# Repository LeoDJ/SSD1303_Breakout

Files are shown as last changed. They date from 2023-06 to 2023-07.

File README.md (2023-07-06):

# SSD1303 Breakout Board

A breakout board for a specific SSD1303 OLED display.  
Optimized for low-cost PCB assembly services from a specific chinese manufacturer with blue logo.

You can [preview the PCB](https://kicanvas.org/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) using the amazing KiCanvas. (Or the [schematic](https://kicanvas.org/?github=https%3A%2F%2Fgithub.com%2FLeoDJ%2FSSD1303_Breakout%2Ftree%2Fmain) if I forget to update the [PDF](./SSD1303_Breakout.pdf) ^^' )

## Pinout
| Pin | Function |
|-----|---|
| GND | GND |
| VCC | 3.3 - 5 V (up to ~250mA[^1]) |
| CLK | SPI: `SCK` <br>I²C: `SCL` |
| DI  | SPI: `MOSI` <br>I²C: `SDA` |
| RES | Reset (active low) |
| DC  | SPI: data/command line <br>I²C: address. 0: `0x3C` / 1: `0x3D` (default low) |
| CS  | SPI: `CS` |

* I/O pins are 5V tolerant
* To switch between SPI and I²C mode, you need to bridge / unbridge the solder jumper at the back (default is SPI)
* I've tried to make the pinout as compatible as possible to existing OLED modules, but there are many different variants

[^1]: Might draw up to ~250 mA @ 3.3V with all pixels on, guesstimated.  
I've measured roughly 50mA @ 12V with the highest brightness and all pixels on, so with pessimistic conversion losses around 750mW.

## Rev 1.0
### Issues
- In SPI mode, the "serial data out" pin of the SSD1303 (pin D2) doesn't always stay high[^2], as was initially measured. Thus the simple diode trick to allow both SPI and I²C mode, without needing to "keep D2 disconnected in SPI mode" as stated in the datasheet, won't work.
  - **Workaround**: Remove D1 (below the FPC) for working SPI mode
  - Fix in next revision: An additional FET in series to the D2 signal that gets activated by the solder jumper
- An additional solder jumper for I²C address would probably be nice
  - In case one wants to use the breakout board on a 4-pin-only socket
  - **Workaround**: solder a jumper wire from the DC pin/pad to the VCC pin/pad to select address `0x3D`

[^2]: It appears to shift out some kind of data, maybe from an internal register. The SSD1303 datasheet doesn't give any hint to the behaviour of pin D2 in SPI mode, except to keep it disconnected.  
Over time the value that gets shifted out accumulates 1 bits. Starting at some random value with few bits set on power-up. (It probably turns into a constant high signal as soon as it reaches 0xFF, but I could only actually observe it up to 0x7F/0xF7 in my last measurement.)  
When the pin is actively pulled low by the SSD1303, it interferes through the diode D1 with the actual data meant for the data input pin D1.  

### Screenshots of 3D view
Somehow I got a bit carried away for a relatively simple design, but otoh I've learned a lot again.

<p float="left" style="display: flex; flex-wrap: wrap; align-items: center;">
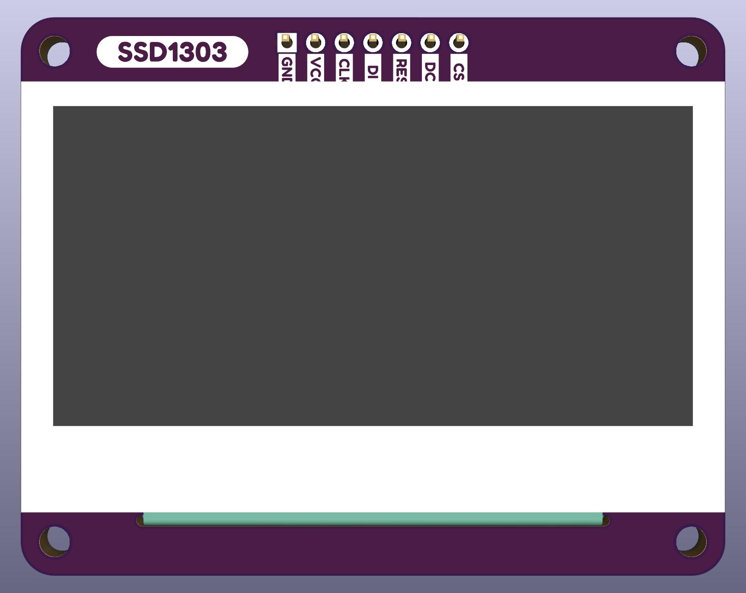
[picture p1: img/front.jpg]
  &nbsp;
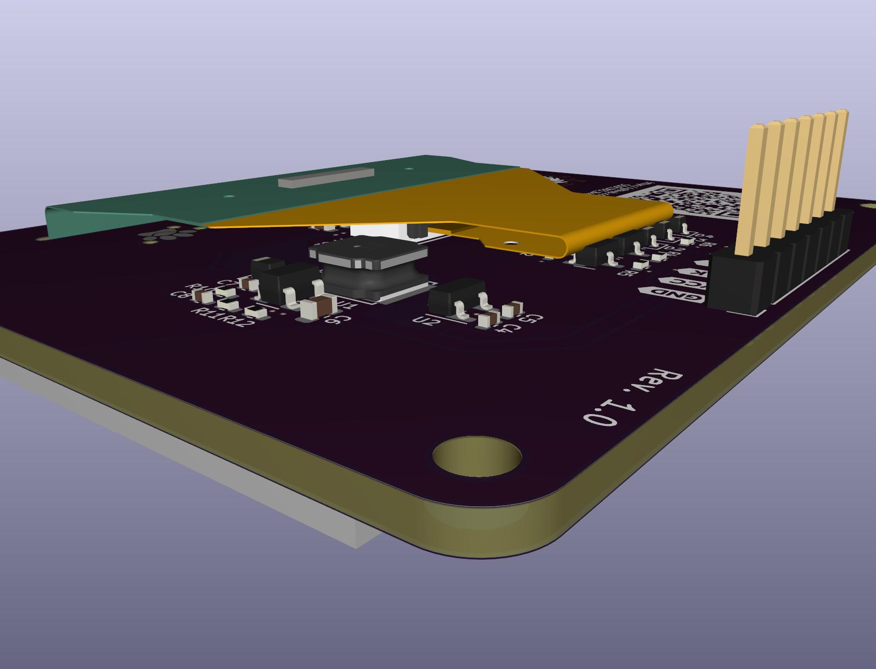
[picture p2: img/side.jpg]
  
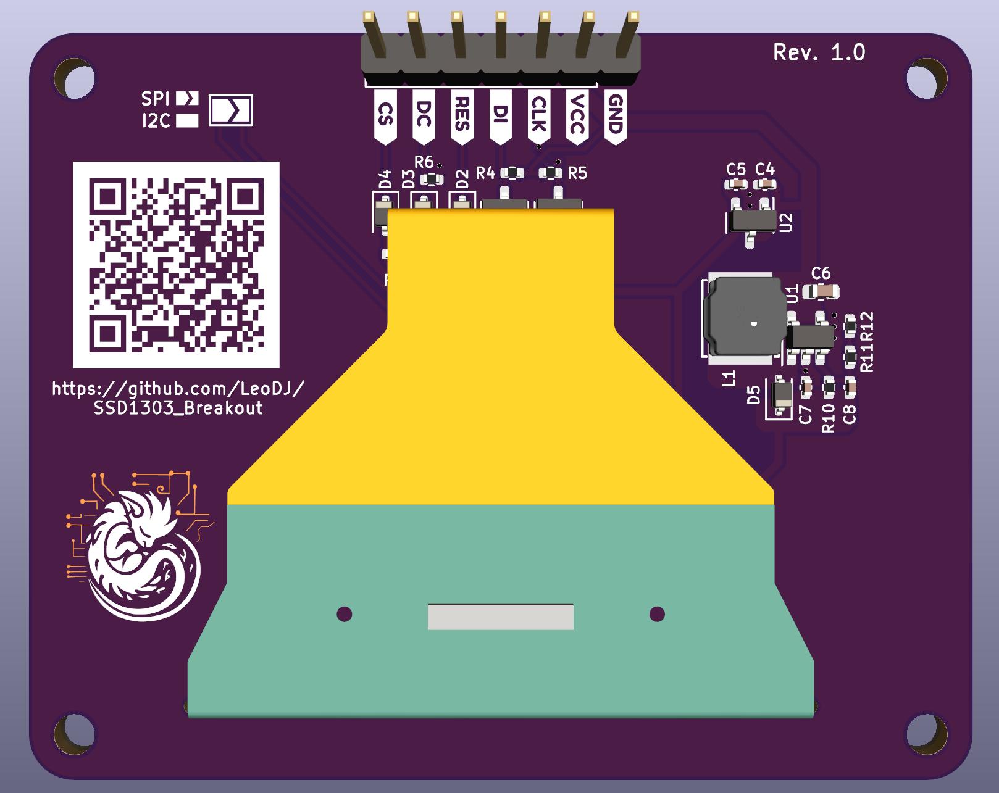
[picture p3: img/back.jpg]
  &nbsp;
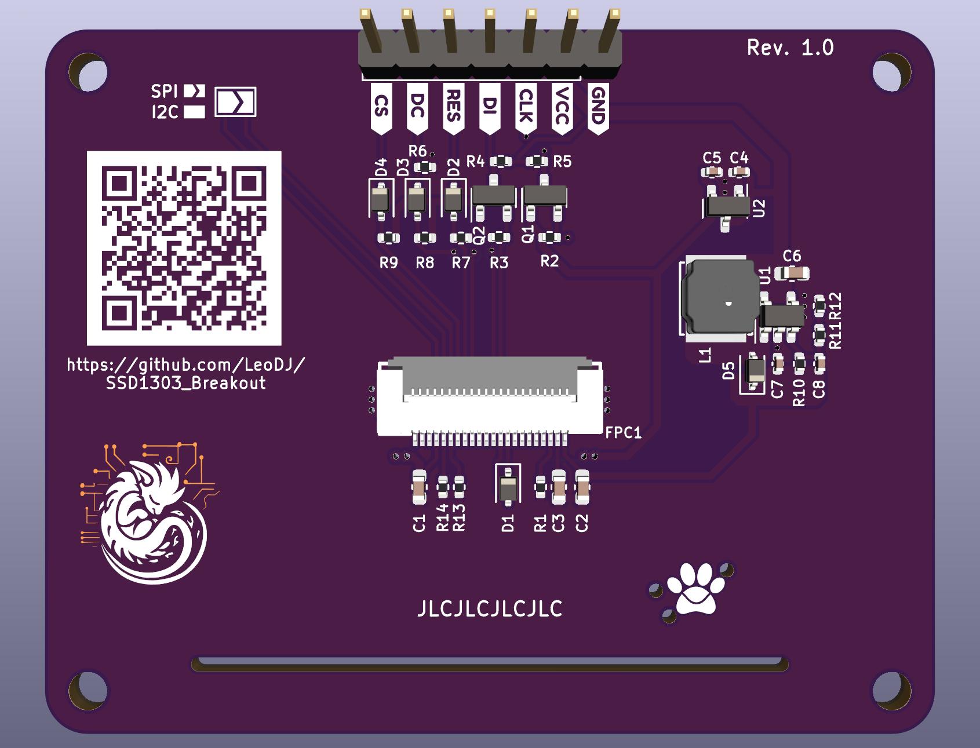
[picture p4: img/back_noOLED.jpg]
  
</p>

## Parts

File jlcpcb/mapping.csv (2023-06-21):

Footprint | Part Value | LCSC Part
C_0402_1005Metric | 1u | C52923
C_0402_1005Metric | 1uF/25V | C52923
C_0402_1005Metric | 10p | C32949
C_0603_1608Metric | 10u | C96446
C_0603_1608Metric | 10uF/25V | C96446
D_SOD-323 | 1N5819WS | C191023
FFC-SMD_22P-P0.50-P0.50_LW05201-22 | LW05201-22 | C375902
IND-SMD_L5.0-W5.0 | 10uH/<250mΩ | C963773
R_0402_1005Metric | 1M | C26083
R_0402_1005Metric | 10k | C25744
R_0402_1005Metric | 100k | C25741
SOT-23 | 2N7002 | C8545
SOT-23-3 | XC6206P332MR | C5446
SOT-23-5 | TPS61040DBV | C7722
TE_2-1734839-2_1x22-1MP_P0.5mm_Horizontal | Conn_01x23 | C375902

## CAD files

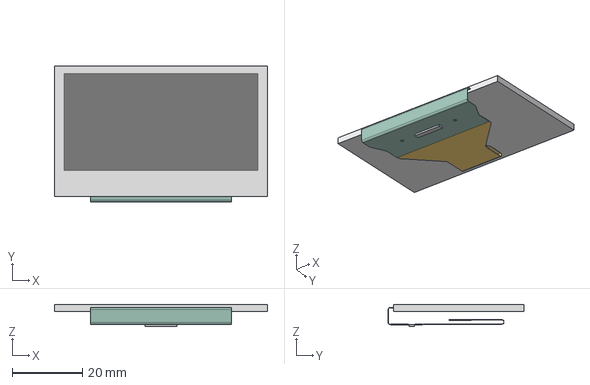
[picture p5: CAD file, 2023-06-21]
EPR1200043B SSD1303 OLED bent 1.6mm.step
60.5 x 38.6 x 6.38 mm

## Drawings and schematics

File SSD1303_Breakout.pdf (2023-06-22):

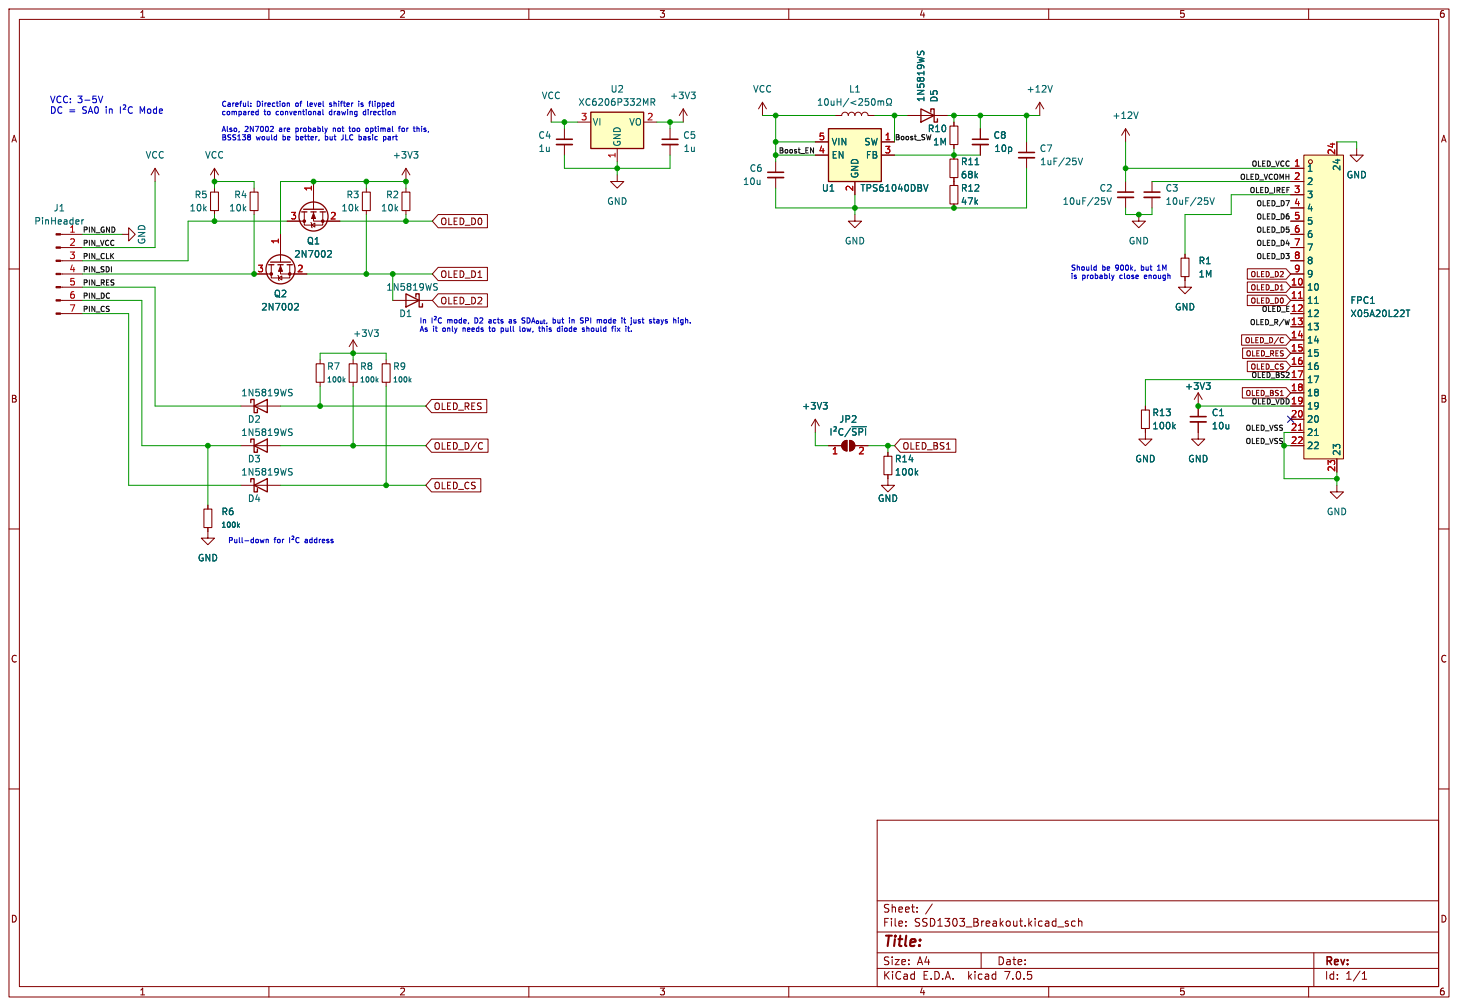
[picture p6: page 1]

2 FB 3 EN 4 VIN 5U1 TPS61040DBV GND GND 1N5819WS D5 GND

2 FB 3 EN 4 VIN 5 1N5819WS D5 GND
10uVCC

In þÿI²Cmode, D2 acts as SDA_{out},but in SPI mode it just stays high. As it only needs to pull low, this diode should fix it. VCC: 3-5V DC = SA0 in þÿI²CMode

Id: 1/1 Title: File: SSD1303_Breakout.kicad_sch Sheet: /

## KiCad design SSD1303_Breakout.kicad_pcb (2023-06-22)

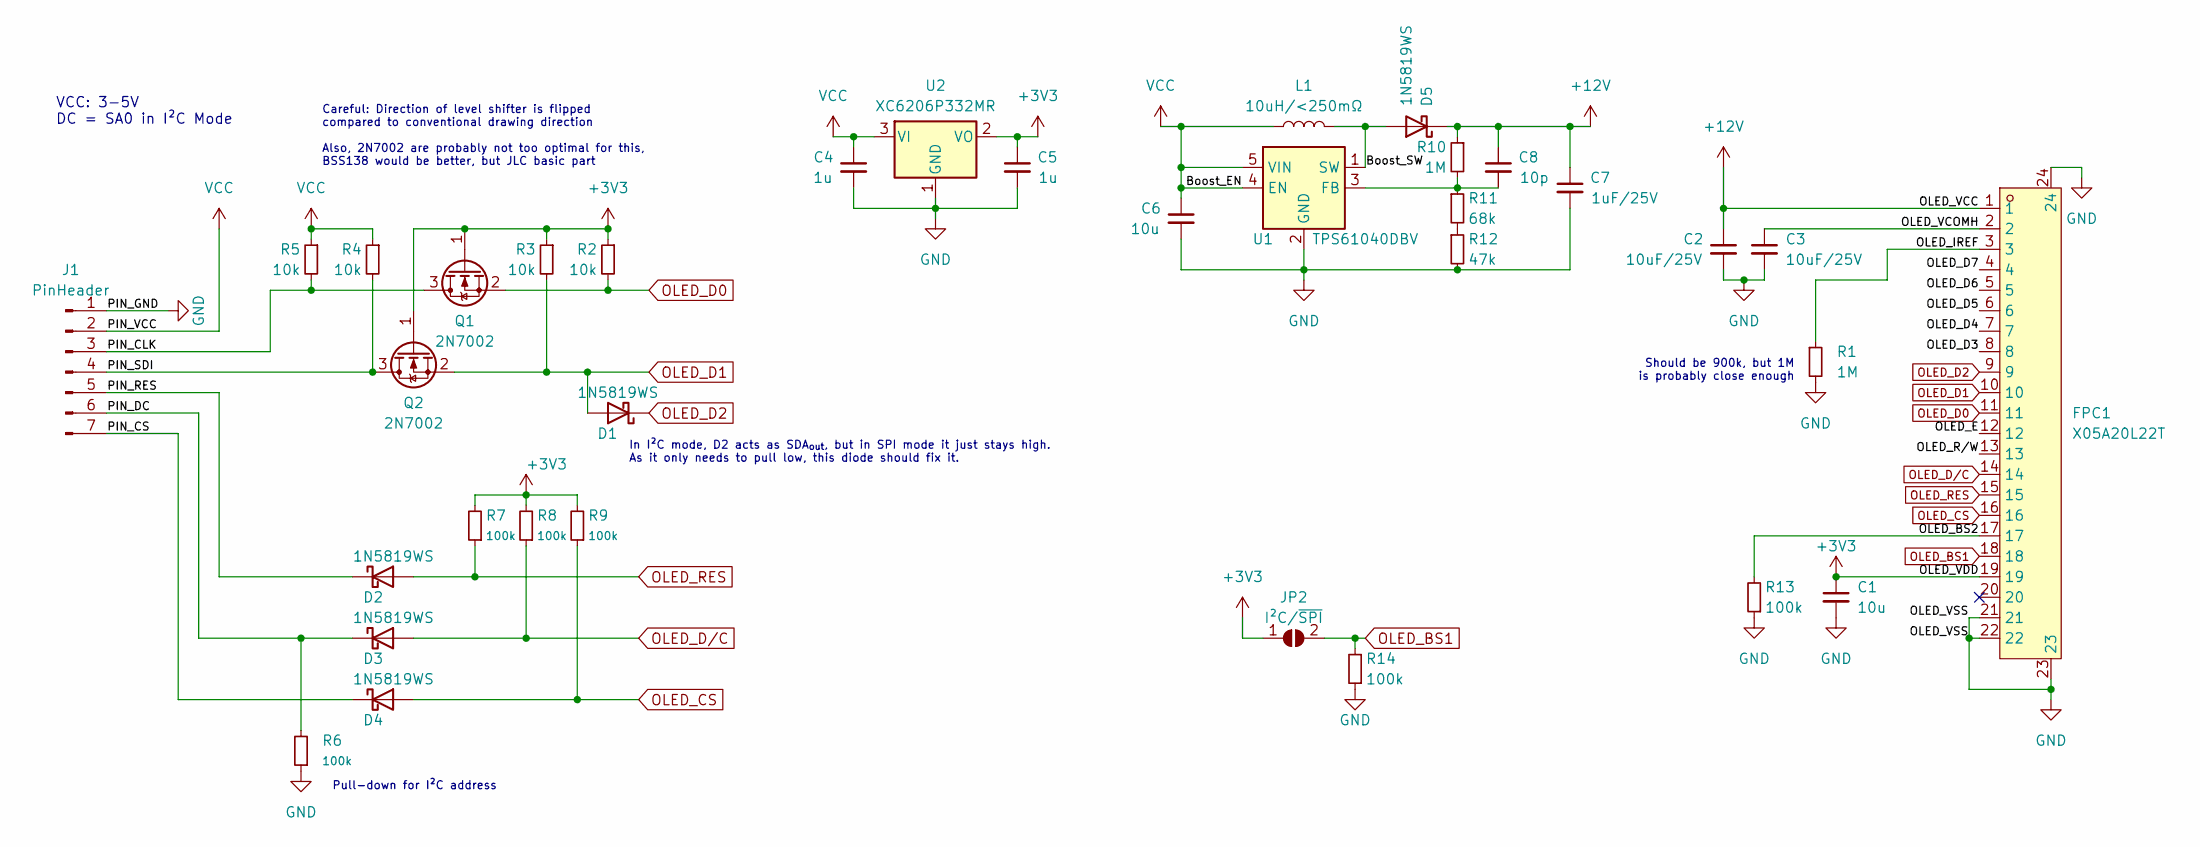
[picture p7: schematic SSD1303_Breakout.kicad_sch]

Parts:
C1, C6: 10u; C_0603_1608Metric; LCSC C96446
C2, C3: 10uF/25V; C_0603_1608Metric; LCSC C96446
C4, C5: 1u; C_0402_1005Metric; LCSC C52923
C7: 1uF/25V; C_0402_1005Metric; LCSC C52923
C8: 10p; C_0402_1005Metric; LCSC C32949
D1, D2, D3, D4, D5: 1N5819WS; D_SOD-323; LCSC C191023
FPC1: X05A20L22T; FFC-SMD_22P-P0.50_X05A20L22T; LCSC Part C388675
J1: PinHeader; PinHeader_1x07_P2.54mm_Vertical
JP2: I²C/~{SPI}; SolderJumper-2_P1.3mm_Open_TrianglePad1.0x1.5mm
L1: 10uH/<250mΩ; IND-SMD_L5.0-W5.0; LCSC C963773
Q1, Q2: 2N7002; SOT-23; LCSC C8545
R1, R10: 1M; R_0402_1005Metric; LCSC C26083
R2, R3, R4, R5: 10k; R_0402_1005Metric; LCSC C25744
R6, R7, R8, R9, R13, R14: 100k; R_0402_1005Metric; LCSC C25741
R11: 68k; R_0402_1005Metric; LCSC C36871
R12: 47k; R_0402_1005Metric; LCSC C25792
U1: TPS61040DBV; SOT-23-5; LCSC C7722
U2: XC6206P332MR; SOT-23; LCSC C5446

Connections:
+3V3: C1.1, C5.1, FPC1.19, JP2.1 (A), Q1.1 (G), Q2.1 (G), R2.1, R3.1, R7.2, R8.2, R9.2, U2.2 (VO)
+12V: C2.1, C7.1, C8.1, D5.1 (K), FPC1.1, R10.1
/Boost_SW: D5.2 (A), L1.2, U1.1 (SW)
/OLED_BS2: FPC1.17, R13.2
/OLED_D3: FPC1.8
/OLED_D4: FPC1.7
/OLED_D5: FPC1.6
/OLED_D6: FPC1.5
/OLED_D7: FPC1.4
/OLED_E: FPC1.12
/OLED_IREF: FPC1.3, R1.1
/OLED_R/W: FPC1.13
/OLED_VCOMH: C3.1, FPC1.2
/PIN_CLK: J1.3, Q1.3 (D), R5.2
/PIN_CS: D4.1 (K), J1.7
/PIN_DC: D3.1 (K), J1.6, R6.2
/PIN_RES: D2.1 (K), J1.5
/PIN_SDI: J1.4, Q2.3 (D), R4.2
GND: C1.2, C2.2, C3.2, C4.2, C5.2, C6.2, C7.2, FPC1.21, FPC1.22, FPC1.23, FPC1.24, J1.1, R1.2, R6.1, R12.2, R13.1, R14.1, U1.2 (GND), U2.1 (GND)
unnamed: R11.2, R12.1
unnamed: C8.2, R10.2, R11.1, U1.3 (FB)
OLED_BS1: FPC1.18, JP2.2 (B), R14.2
OLED_CS: D4.2 (A), FPC1.16, R9.1
OLED_D0: FPC1.11, Q1.2 (S), R2.2
OLED_D1: D1.2 (A), FPC1.10, Q2.2 (S), R3.2
OLED_D2: D1.1 (K), FPC1.9
OLED_D/C: D3.2 (A), FPC1.14, R8.1
OLED_RES: D2.2 (A), FPC1.15, R7.1
VCC: C4.1, C6.1, J1.2, L1.1, R4.1, R5.1, U1.4 (EN), U1.5 (VIN), U2.3 (VI)

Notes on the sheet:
Should be 900k, but 1M is probably close enough
In I²C mode, D2 acts as SDA_{out}, but in SPI mode it just stays high. As it only needs to pull low, this diode should fix it.
Pull-down for I²C address
Careful: Direction of level shifter is flipped compared to conventional drawing direction Also, 2N7002 are probably not too optimal for this, BSS138 would be better, but JLC basic part
VCC: 3-5V DC = SA0 in I²C Mode

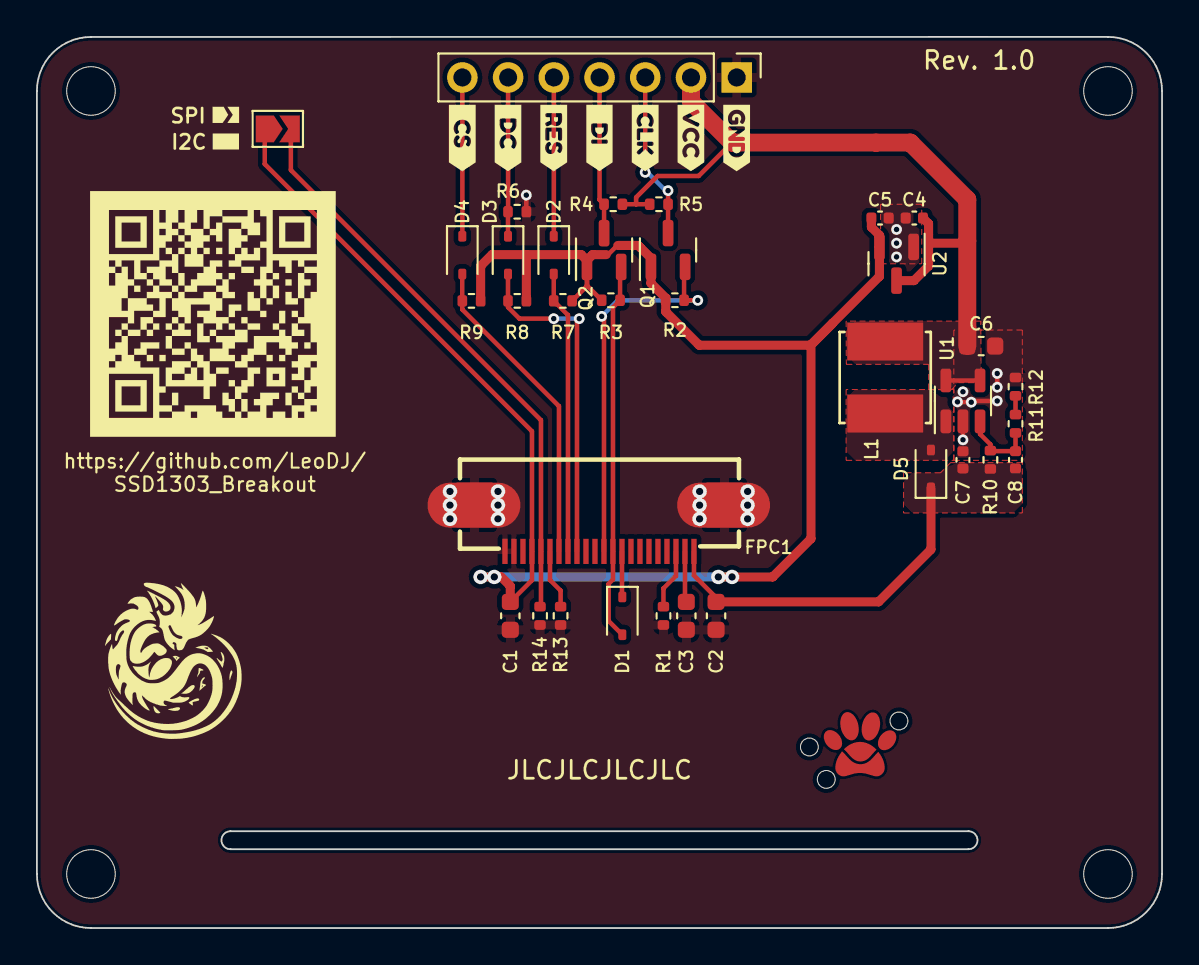
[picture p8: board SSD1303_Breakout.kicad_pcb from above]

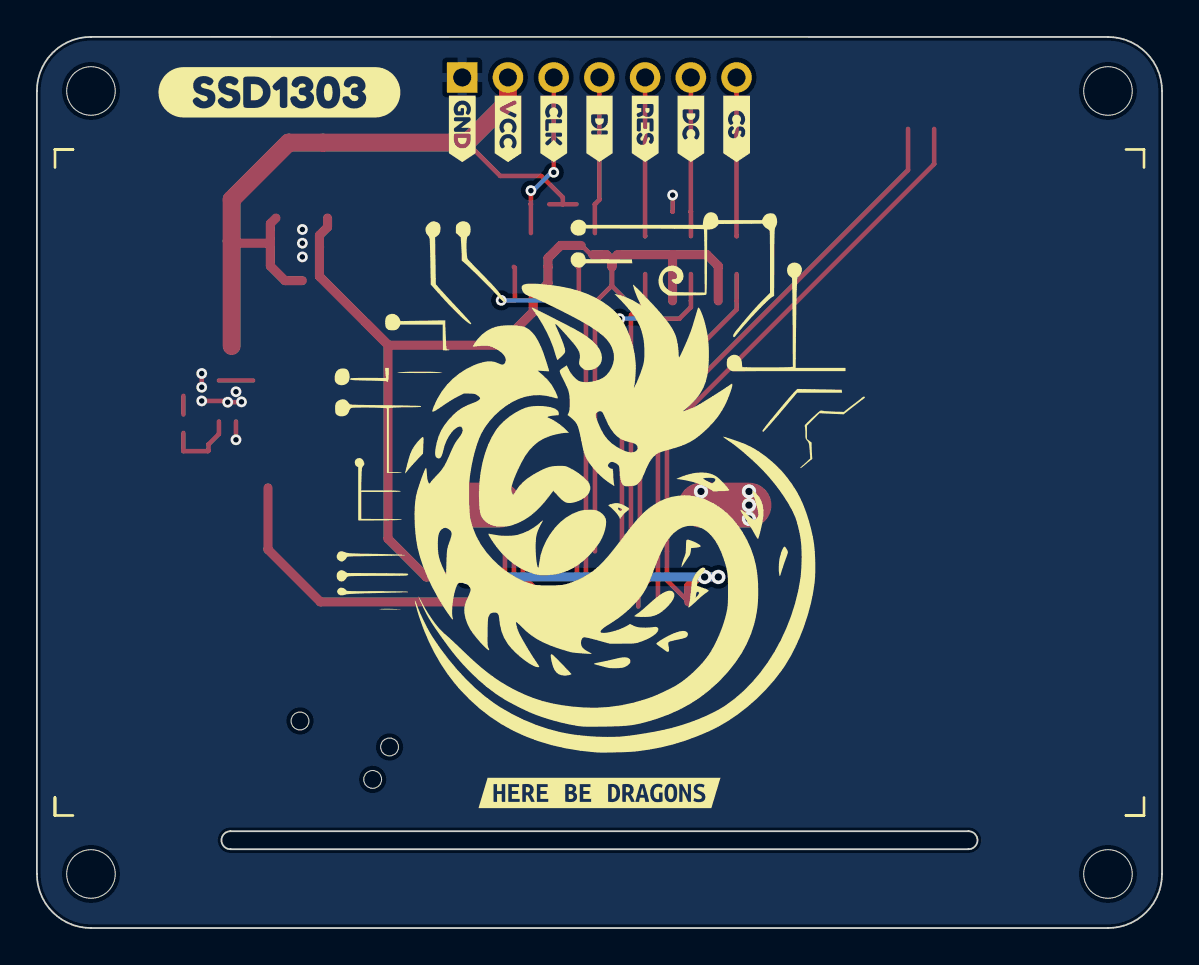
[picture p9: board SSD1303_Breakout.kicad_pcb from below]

Board: 2 copper layers, 62.5 x 49.5 mm, 51 parts (9 on the bottom side), 22 nets.

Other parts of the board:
kibuzzard-6492A15D: G***; kibuzzard-6492A15D
kibuzzard-649270A0, kibuzzard-649270A0#2: G***; kibuzzard-649270A0
kibuzzard-649270A6, kibuzzard-649270A6#2: G***; kibuzzard-649270A6
kibuzzard-649270AD, kibuzzard-649270AD#2: G***; kibuzzard-649270AD
kibuzzard-649270B3, kibuzzard-649270B3#2: G***; kibuzzard-649270B3
kibuzzard-649270BA, kibuzzard-649270BA#2: G***; kibuzzard-649270BA
kibuzzard-6492708E, kibuzzard-6492708E#2: G***; kibuzzard-6492708E
kibuzzard-64927098, kibuzzard-64927098#2: G***; kibuzzard-64927098
kibuzzard-64927129: G***; kibuzzard-64927129

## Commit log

2023-06-21 mainly done, some minor touchups still todo
    [EPR1200043B SSD1303 OLED bent 1.6mm.step, SSD1303_Breakout.kicad_pcb, SSD1303_Breakout.kicad_sch]
2023-06-21 add preliminary fabrication outputs
    [BOM-SSD1303_Breakout.csv, mapping.csv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]
2023-06-22 final™ touches
    [BOM-SSD1303_Breakout.csv, SSD1303_Breakout.kicad_pcb, SSD1303_Breakout.kicad_sch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]
